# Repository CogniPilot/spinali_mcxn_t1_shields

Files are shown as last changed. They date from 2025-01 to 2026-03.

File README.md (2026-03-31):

# MR-MCXN-T1 Add-on boards

> [!NOTE]
> Different Add-on boards have been designed for the modular multi-purpose [MR-MCXN-T1 Hub](https://github.com/CogniPilot/spinali_mcxn_t1_hub). 
>
> The following add-on boards have been designed:
> - Optical Flow
> - IO
> - GNSS (with F9P module) [^1]
> 
> All add-on boards are designed with KiCAD.
>
> [^1]: GNSS add-on is still in the design process.

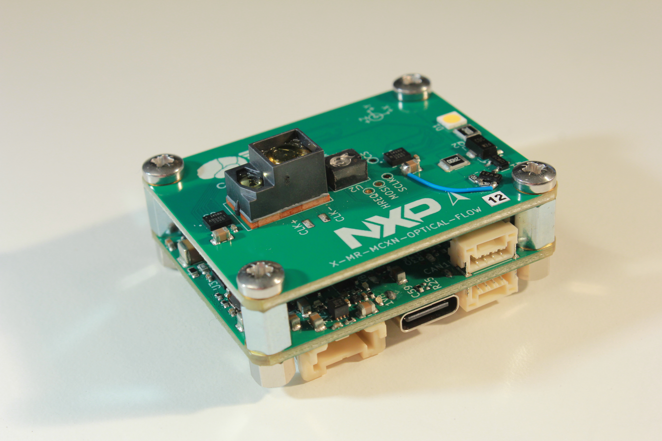
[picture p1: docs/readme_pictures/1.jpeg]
Hub with Optical Flow add-on

<sup>Example of Optical Flow add-on board stacked on MR-MCXN-T1 Hub</sup>

# MR-MCXN-T1 Optical Flow

> [!NOTE]
> The Optical Flow add-on board can be used in for instance UAVs and UGVs for localization and navigation using the following on-board sensors:
> - Time of Flight (AFBR-S50LX85D)
> - Optical Flow (PAA3905E1) + required light source
> - IMU 2x (ICM-45686 & ICM42688)

<details>
<summary>MR-MCXN-T1 Optical Flow pictures</summary>
  
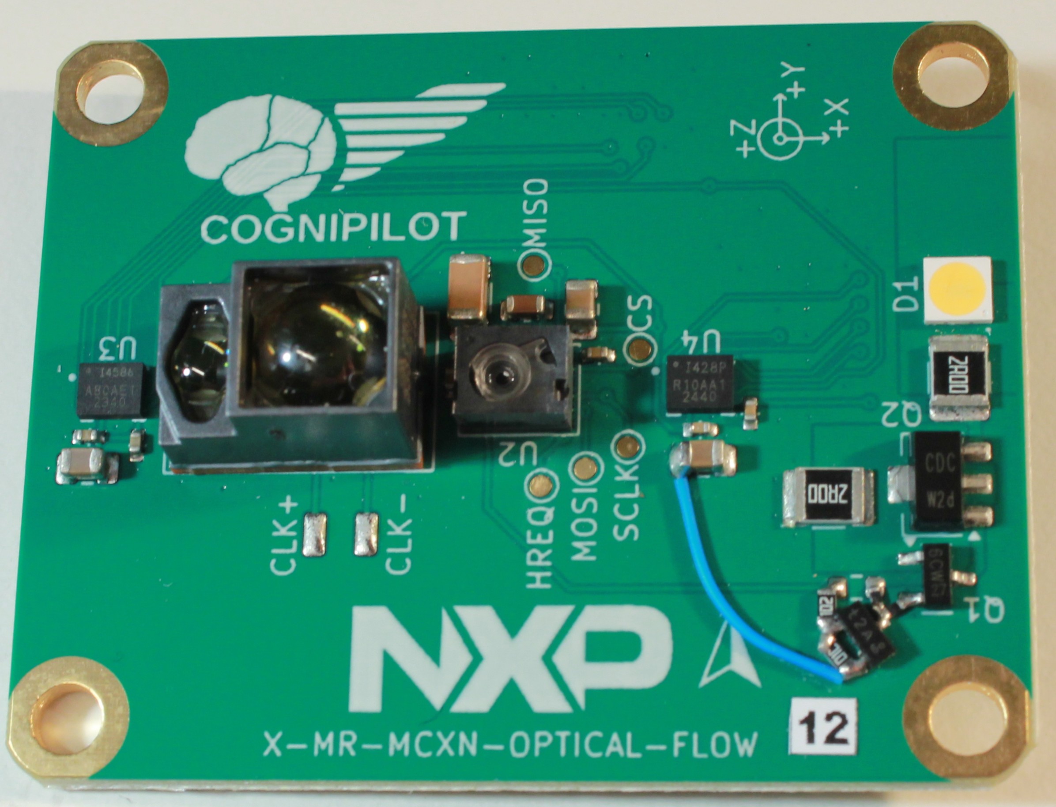
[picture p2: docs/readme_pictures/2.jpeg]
Optical Flow Cropped

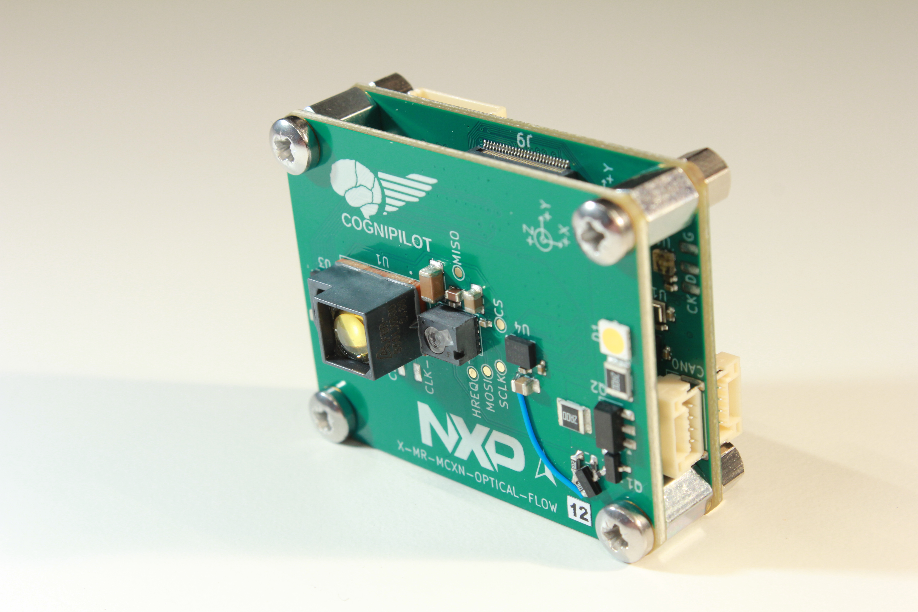
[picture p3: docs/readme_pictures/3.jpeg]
Optical Flow Side


</details>

# MR-MCXN-T1 IO

> [!Note]
> MR-MCXN-T1 IO board brings out almost all GPIO to JST connectors. These are as follows:
> | IO type      | Connector type |
> | ----------- | ----------- |
> | UART 2x | JST GH 6-pin |
> | SPI 2x | JST GH 7-pin |
> | I2C 2x | JST GH 4-pin |
> | GPS | JST GH 10-pin |
> | Quadrature Decoder | JST GH 6-pin |
> | 4in1 ESC 2x | JST GH 8-pin |
> | External battery input for RTC | JST GH 2-pin |
> 
> If applicable the connector pinouts follow the [DS-009 Connector Standard](https://github.com/pixhawk/Pixhawk-Standards/blob/master/DS-009%20Pixhawk%20Connector%20Standard.pdf).

<details>
<summary>MR-MCXN-T1 IO pictures</summary>
  
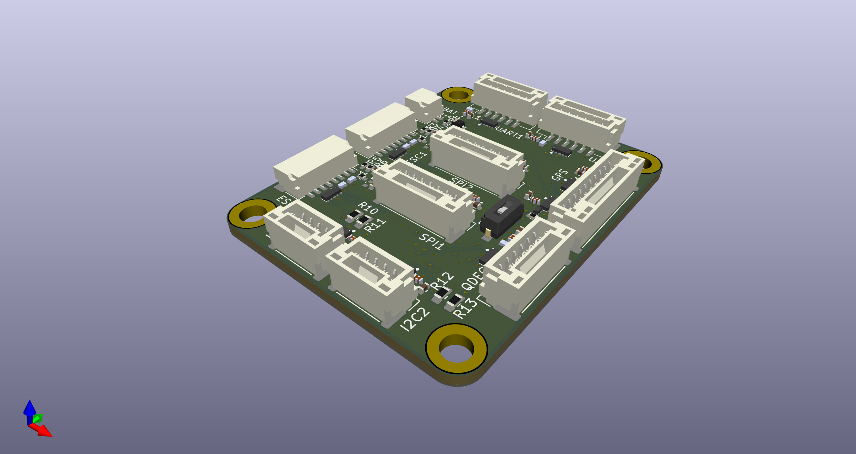
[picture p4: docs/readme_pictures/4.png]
IO Board Side

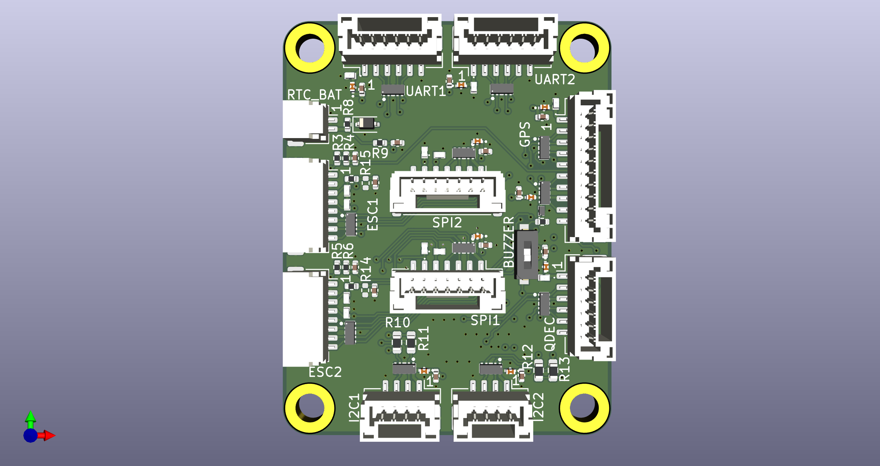
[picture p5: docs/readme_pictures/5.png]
IO Board Top


</details>

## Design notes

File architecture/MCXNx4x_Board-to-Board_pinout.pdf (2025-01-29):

X0A | | Pin | Pad type | ADC | Optical flow | Mikrobus adapter | GPS | Optical flow + GPS | Camera head | Display | Microphone | Opamp | Motor control | Dual motor control | Speaker driver | SDIO shield | Trace DBG
1 PGND
3 5V
5 5V
7 5V
9 PGND
11 PGND
13 VDD_BAT
15 3V3
17 | T17 | 3V3
19 PGND
21 PGND
23 | P4_0 | FC2_P0 | slow | | | | | FC2_P0
25 | P4_1 | FC2_P1 | slow | | | | | FC2_P1
27 GND
29 | P4_2 | FC2_P2 | slow | ADC0_A4/ADC1_A4 | | | | FC2_P2 | | | | | CMP1_IN4N | CMP1_IN4N | DAC0_OUT
31 | P4_3 | FC2_P3 | slow | ADC0_B4/ADC1_B4 | | | | FC2_P3 | | | | | CMP1_IN5N | CMP1_IN5N | DAC1_OUT
33 GND
35 | P4_23 | FC2_P6 | slow | ADC0_A2/ADC0_B2/ADC1_B3 | | | | FC2_P6 | | | | OPAMP2_OUT | | CMP2_IN4P
37 | P4_20 | FC2_P4 | slow | ADC1_A6 | | | | FC2_P4 | | FLEXIO0_D28 | | OPAMP2_INP0
39 GND
41 | ANA_22 | OPAMP2_INN | | | | | | | | | | OPAMP2_INN
43 | ANA_6 | DAC2_OUT | | ADC0_A3/ADC1_A3 | | | | | | | | | | | DAC2_OUT
45 GND
47 | P0_23 | FLEXIO0_D7 | med | ADC0_A15 | | | | | | FLEXIO0_D7 | | | | CMP2_IN2
49 GND
X0B | | Pin | Pad type | ADC | Optical flow | Mikrobus adapter | GPS | Optical flow + GPS | Camera head | Display | Microphone | Opamp | Motor control | Dual motor control | Speaker driver | SDIO shield | Trace DBG
2 PGND
4 5V
6 5V
8 5V
10 PGND
12 PGND
14 3V3
16 3V3
18 PGND
20 PGND
22 1V8
24 PGND
26 | P1_8 | FC4_P0 | med | ADC1_A8 | I3C1_SDA | ADC1_A8 | | I3C1_SDA | I3C1_SDA
28 | P1_9 | FC4_P1 | med | ADC1_A9 | I3C1_SCL | ADC1_A9 | | I3C1_SCL | I3C1_SCL
30 GND
32 | P3_1 | FC6_P0 | fast | | SPI_SDO | SPI_SDO | | SPI_SDO | SmartDMA_PIO1 | | | | | PWM0_B0
34 | P3_6 | FC6_P1 | fast | | SPI_SCK | SPI_SCK | | SPI_SCK | SmartDMA_PIO6 | | | | | PWM0_A1
36 GND
38 | P3_10 | FC6_P2 | fast | | SPI_SDI | SPI_SDI | | SPI_SDI | SmartDMA_PIO10 | FLEXIO0_D18 | | | | PWM0_A3
40 | P3_11 | FC6_P3 | fast | | SPI_CS0 | SPI_CS0 | | SPI_CS0 | SmartDMA_PIO11 | FLEXIO0_D19 | | | | PWM0_B3
42 | P3_18 | FC6_P6 | fast | | SPI_HREQ | SPI_HREQ | | SPI_HREQ | SmartDMA_PIO18
44 GND
46 | 2_10 | TRACE_DATA2 | fast | | | | | | | | | | | | | | TRACE_DATA2
48 | 2_11 | TRACE_DATA3 | fast | | | | | | | | | | | | | | TRACE_DATA3
50 GND

X1A | | Pin | Pad type | ADC | Optical flow | Mikrobus adapter | GPS | Optical flow + GPS | Camera head | Display | Microphone | Opamp | Motor control | Dual motor control | Speaker driver | SDIO shield | Trace DBG
1 GND
3 | P2_5 | uSDHC0_CMD | fast | | FC9_P2 | SPI_SDI | | FC9_P2 | SmartDMA_PIO25 | FLEXIO0_D13 | | | PWM1_B1 | PWM1_B1 | SAI0_TXD1 | uSDHC0_CMD
5 | P2_4 | uSDHC0_CLK | fast | | FC9_P0 | SPI_SDO | | FC9_P0 | SmartDMA_PIO24 | FLEXIO0_D12 | | | PWM1_A1 | PWM1_A1 | SAI0_RXD1 | uSDHC0_CLK
7 GND
9 | P2_3 | uSDHC0_D0 | fast | | FC9_P1 | SPI_SCK | | FC9_P1 | SmartDMA_PIO23 | FLEXIO0_D11 | | | PWM1_B2 | PWM1_B2 | SAI0_RXD0 | uSDHC0_D0
11 | P2_2 | uSDHC0_D1 | fast | | FC9_P3 | SPI_CS0 | | FC9_P3 | CLKOUT | FLEXIO0_D10 | | | PWM1_A2 | PWM1_A2 | SAI0_TXD0 | uSDHC0_D1
13 GND
15 | P2_7 | uSDHC0_D2 | fast | | | | | | SmartDMA_PIO27 | FLEXIO0_D15 | | | PWM1_B0 | PWM1_B0 | SAI0_TX_FS | uSDHC0_D2
17 | P2_6 | uSDHC0_D3 | fast | | | PWM1_A0 | | | SmartDMA_PIO26 | FLEXIO0_D14 | | | PWM1_A0 | PWM1_A0 | SAI0_TX_BCLK | uSDHC0_D3
19 GND
21 | P2_1 | uSDHC0_D4 | fast | | | RST2 | | | SmartDMA_PIO21 | FLEXIO0_D9 | | | PWM1_B3 | PWM1_B3 | SAI0_RX_FS | uSDHC0_D4 | TRACE_CLK
23 | P2_0 | uSDHC0_D5 | fast | | FC9_P6 | SPI_HREQ | | FC9_P6 | SmartDMA_PIO20 | FLEXIO0_D8 | | | PWM1_A3 | PWM1_A3 | SAI0_RX_BCLK | uSDHC0_D5
25 GND
27 | P2_9 | uSDHC0_D6 | fast | | | RST1 | | | SmartDMA_PIO29 | FLEXIO0_D17 | | | | | | uSDHC0_D6 | TRACE_DATA1
29 | P2_8 | uSDHC0_D7 | fast | | | | | | SmartDMA_PIO28 | FLEXIO0_D16 | | | | | | uSDHC0_D7 | TRACE_DATA0
31 GND
33 | P3_2 | FC7_P0 | fast | | SPI_SDO | I2C_SDA | FC7_P0 | SPI_SDO | I2C_SDA
35 | P3_3 | FC7_P1 | fast | | SPI_SCK | I2C_SCL | FC7_P1 | SPI_SCK | I2C_SCL
37 GND
39 | P3_4 | FC7_P2 | fast | | SPI_SDI | UART_TXD | FC7_P2 | SPI_SDI | UART_TXD
41 | P3_5 | FC7_P3 | fast | | SPI_CS0 | UART_RXD | FC7_P3 | SPI_CS0 | UART_RXD
43 GND
45 | P3_19 | FC7_P6 | fast | | SPI_HREQ | HREQ | FC7_P6 | SPI_HREQ | HREQ | FLEXIO0_D27
47 | P3_12 | FC7_P4 | fast | | | | | | SmartDMA_PIO12 | FLEXIO0_D20
49 GND
X1B | | Pin | Pad type | ADC | Optical flow | Mikrobus adapter | GPS | Optical flow + GPS | Camera head | Display | Microphone | Opamp | Motor control | Dual motor control | Speaker driver | SDIO shield | Trace DBG
2 GND
4 | P3_0 | SmartDMA_PIO0 | fast | | | PWM0_A0 | | | SmartDMA_PIO0 | | | | | PWM0_A0
6 | P3_7 | SmartDMA_PIO7 | fast | | | | | | SmartDMA_PIO7 | | | | | PWM0_B1
8 GND
10 | P3_8 | SmartDMA_PIO8 | fast | | | | | | SmartDMA_PIO8 | | | | | PWM0_A2
12 | P3_9 | SmartDMA_PIO9 | fast | | | | | | SmartDMA_PIO9 | | | | | PWM0_B2
14 GND
16 | P1_0 | FC3_P0 | med | ADC0_A16 | | I2C_SDA | | | | I2C_SDA | | | ADC0_A16 | ADC0_A16
18 | P1_1 | FC3_P1 | med | ADC0_A17 | | I2C_SCL | | | | I2C_SCL | | | CMP1_IN0 | CMP1_IN0
20 GND
22 | P1_2 | FC3_P2 | med | ADC0_A18 | | UART_TXD | | | | | | | | CMP2_IN0
24 | P1_3 | FC3_P3 | med | ADC0_A19 | | UART_RXD | | | | | | | ADC0_A19 | ADC0_A19
26 GND
28 | P1_18 | FC3_P6 | med | ADC1_A18 | | HREQ | | | SmartDMA_PIO14 | FLEXIO0_D26
30 GND
32 | P1_16 | FC3_P4 | med | ADC1_A16 | FC5_P0 | | | | | FLEXIO0_D24
34 | P1_17 | FC3_P5 | med | ADC1_A17 | FC5_P1 | | | | | FLEXIO0_D25
36 GND
38 | P0_16 | FC0_P0 | med | ADC0_A8 | | ADC0_A8 | | | | | PDM0_CLK | | | ADC0_A8
40 | P0_17 | FC0_P1 | med | ADC0_A9 | | | | | | | PDM0_DATA0 | | | ADC0_A9
42 GND
44 | P0_18 | FC0_P2 | med | ADC0_A10 | | ADC0_A10 | | | | | PDM0_DATA1 | | | ADC0_A10
46 | P0_7 | FC0_P3 | med | | | | | | | | | | | CMP2_IN1
48 | P0_22 | FC0_P6 | med | ADC0_A14 | | | | | | FLEXIO0_D6 | | | CMP1_IN2 | CMP1_IN2
50 GND

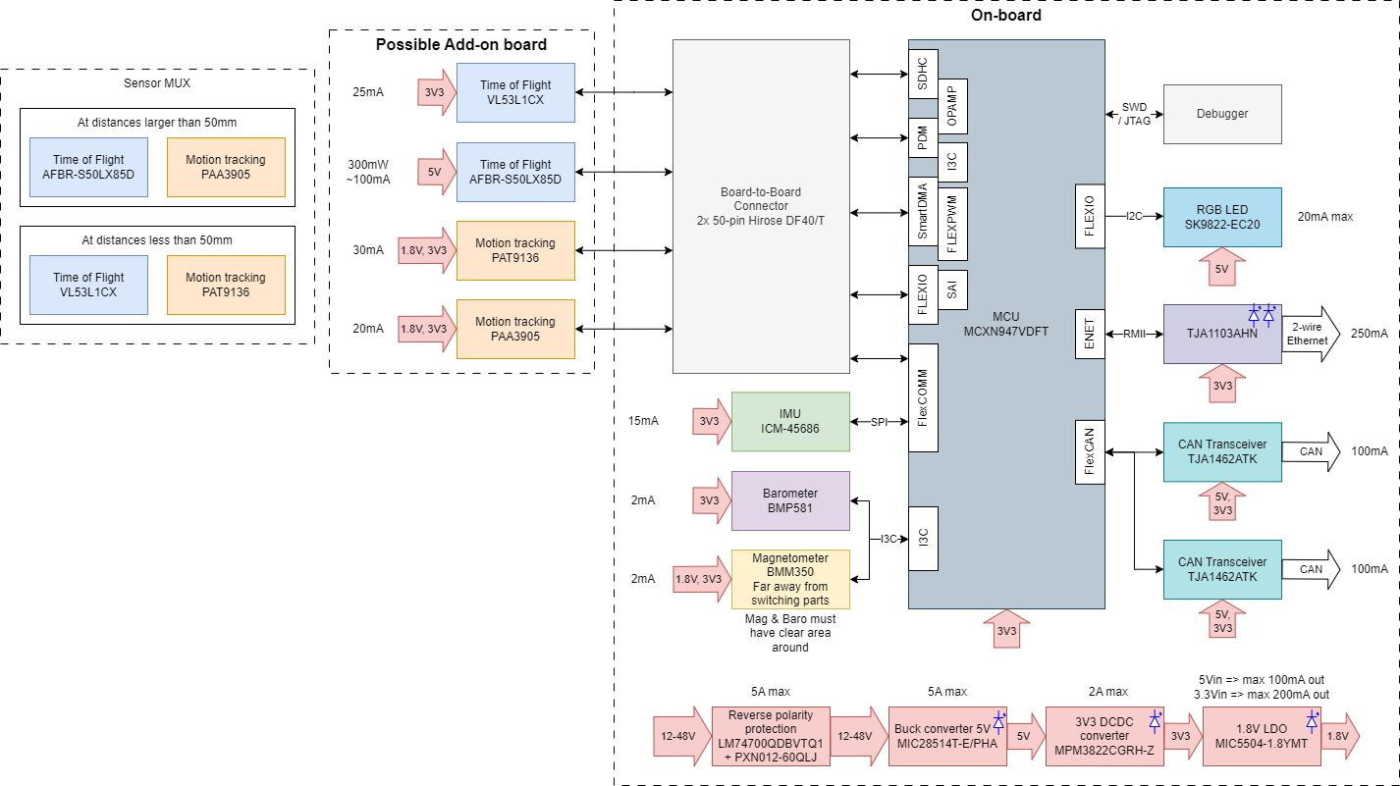
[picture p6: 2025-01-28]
architecture/Architecture diagram-New Concept modulair Sensor hub.drawio.png

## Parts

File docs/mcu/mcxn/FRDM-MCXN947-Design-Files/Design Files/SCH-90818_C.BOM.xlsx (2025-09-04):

 | ManufacturerBomReport
Type | Part
Classification | Sales Item/Commercial Boards/Evaluation Board or Silicon Validation
Item Number | 935455837598
Name | FRDM-MCXN947
Description | FRDM-MCXN947
Lifecycle | RFS
Item Revision | A1
Change Item
Created By: | Kate Fan
Create Time: | 4/1/2024 4:59 AM
Level | Type | Classification | Item Number | Name | Description | Lifecycle | Item Revision | Change Item | Quantity | Reference Designator | Find Num | BOM Notes | Manufacturer Item Number | Manufacturer Name | Manufacturer | Manufacturer Lifecycle | Manufacturer Notes | Preferred Status
0 | Part | Sales Item/Commercial Boards/Evaluation Board or Silicon Validation | 935455837598 | FRDM-MCXN947 | FRDM-MCXN947 | RFS | A1 |  |  |  |  |  | 246025 | FRDM-MCXN947 | Trivo (Taicang) Technologies Co Ltd | Active |  | Preferred
1 | Part | Boards/Non CAD Parts/Assembly | 745000379172 | 975-90818 | HW PACKOUT, FRDM-MCXN947 | RFS | A1 | ECO30008196 | 1 |  | 1
2 | Part | Boards/CAD Parts/Component | 745000042610 | 211-79847 | SHUNT -- 0.1IN SP JMPR -- AU BLACK | RFS | A |  | 2 |  | 50 |  | 285268 | M7582-05 | HARWIN INC | ROHS Active |  | Preferred
2 | Part | Boards/CAD Parts/Component | 745000042610 | 211-79847 | SHUNT -- 0.1IN SP JMPR -- AU BLACK | RFS | A |  | 2 |  | 50 |  | 299066 | SNT-100-BK-G | SAMTEC | ROHS Active |  | Preferred
2 | Part | Boards/Non CAD Parts/Assembly | 745000281407 | 700-90818 | PWA, FRDM-MCXN947 | RFS | A1 | ECO30010456 | 1 |  | 40 |  | 219145 | 700-90818 | Trivo (Taicang) Technologies Co Ltd | ROHS Active |  | Preferred
2 | Part | Boards/Non CAD Parts/Assembly | 745000281407 | 700-90818 | PWA, FRDM-MCXN947 | RFS | A1 | ECO30010456 | 1 |  | 40 |  | 314140 | 700-90818 | ZHE JIANG XIAN XIN SCIENCE AND TECHNOLOGY CO.LTD | ROHS Active
3 | Part | Boards/Non CAD Parts/Assembly | 745000312196 | 750-90818 | SUB ASSEMBLY, SCHEMATIC PARTS, 700-90818, FRDM-MCXN947 | RFS | C | ECO30010345 | 1 |  | 1000
4 | Part | Boards/CAD Parts/Component | 745000012851 | 150-78886 | CAP CER 0.22UF 16V 10% X7R 0402 | RFS | A |  | 4 | C26,C38,C40,C41 | 0 |  | 200381 | 0402B224K160CT | WALSIN TECHNOLOGY CORP. | Active |  | Preferred
4 | Part | Boards/CAD Parts/Component | 745000012851 | 150-78886 | CAP CER 0.22UF 16V 10% X7R 0402 | RFS | A |  | 4 | C26,C38,C40,C41 | 0 |  | 200603 | 0402B224K160NT | FENGHUA | ROHS Active |  | Alternate
4 | Part | Boards/CAD Parts/Component | 745000012851 | 150-78886 | CAP CER 0.22UF 16V 10% X7R 0402 | RFS | A |  | 4 | C26,C38,C40,C41 | 0 |  | 247691 | GRM155R71C224KA12D | MURATA | Active |  | Alternate
4 | Part | Boards/CAD Parts/Component | 745000013109 | 150-79188 | CAP CER 100pF 16V 10% X7R 0402 | RFS | A |  | 1 | C63 | 0 |  | 200554 | 0402YC101KAT2A | AVX | Active |  | Preferred
4 | Part | Boards/CAD Parts/Component | 745000013463 | 150-79569 | CAP CER 10uF 25V 10% X5R 0603 | RFS | A |  | 0 | C72,C73,C74,C75 | 1504 | DNP | 228855 | C0603X5R106K250NT | SANYEAR | ROHS Active |  | Preferred
4 | Part | Boards/CAD Parts/Component | 745000013463 | 150-79569 | CAP CER 10uF 25V 10% X5R 0603 | RFS | A |  | 9 | C37,C62,C69,C70,C71,C83,C84,C104,C105 | 0 |  | 228855 | C0603X5R106K250NT | SANYEAR | ROHS Active |  | Preferred
4 | Part | Boards/CAD Parts/Component | 745000014519 | 150-80750 | CAP CER 4.7PF 50V 0.5pF C0G 0402 | RFS | A |  | 4 | C1,C2,C100,C101 | 0 |  | 239686 | 885012005053 | WURTH ELEKTRONIK EISOS GMBH & CO. KG (ELECTRONIC & ELECTROMEHANICAL COMP) | Active |  | Preferred
4 | Part | Boards/CAD Parts/Component | 745000015307 | 150-81667 | CAP CER 15pF 50V 5% C0G 0402 | RFS | A |  | 0 | C54,C55,C56,C57 | 1502 | DNP | 273304 | GJM1555C1H150JB01D | MURATA | ROHS Active |  | Preferred
4 | Part | Boards/CAD Parts/Component | 745000047746 | 210-81775 | CON 2X8 SKT SHRD TH 100MIL CTR 345H AU 126L | RFS | A |  | 2 | J1,J3 | 0 |  | 201294 | 08010S31611-29RF | ANYTRONIC CORPORATION LIMITED | ROHS Active |  | Preferred
4 | Part | Boards/CAD Parts/Component | 745000049109 | 210-83442 | CON 2X14 SKT SHRD TH 100MIL CTR 345H AU 126L | RFS | A |  | 1 | J8 | 0 |  | 201317 | 08010S32811-29RF | ANYTRONIC CORPORATION LIMITED | ROHS Active |  | Preferred
4 | Part | Boards/CAD Parts/Component | 745000031874 | 230-78687 | OSC XO 50MHZ 3.3V SMD | RFS | A |  | 1 | Y3 | 0 |  | 266009 | ECS-2333-500-BN-TR | ECS INC. INTERNATIONAL | ROHS Active |  | Preferred
4 | Part | Boards/CAD Parts/Component | 745000019445 | 312-81574 | IC USB PD TYPE C CURRENT LIMITED PWR SW 2.5-5.5V WLCSP12 | RFS | A |  | 1 | U3 | 0 |  | 289609 | NX5P3090UK,012 | NXP SEMICONDUCTOR | Active | Pb-free assembly 260 °C | Preferred
4 | Part | Boards/CAD Parts/Component | 745000019445 | 312-81574 | IC USB PD TYPE C CURRENT LIMITED PWR SW 2.5-5.5V WLCSP12 | RFS | A |  | 1 | U3 | 0 |  | 291065 | NX5P3090UKZ | NXP SEMICONDUCTOR | Active |  | Alternate
4 | Part | Boards/CAD Parts/Component | 745000020844 | 312-83230 | IC XCVR CAN 5MBIT/S 4.75-5.25V AEC-Q100 HVSON8 | RFS | A |  | 1 | U10 | 0 |  | 298760 | TJA1057GTK/3Z | NXP SEMICONDUCTOR | ROHS Active |  | Preferred
4 | Part | Boards/CAD Parts/Component | 745000033390 | 470-30315 | RES MF 470 OHM 1/16W 5% 0402 | RFS | A |  | 10 | R4,R5,R6,R7,R24,R66,R69,R108,R109,R114 | 0 |  | 267838 | ERJ2GEJ471X | PANASONIC | ROHS Active |  | Alternate
4 | Part | Boards/CAD Parts/Component | 745000033390 | 470-30315 | RES MF 470 OHM 1/16W 5% 0402 | RFS | A |  | 10 | R4,R5,R6,R7,R24,R66,R69,R108,R109,R114 | 0 |  | 269357 | RC0402JR-07470RL | YAGEO AMERICA | ROHS Active |  | Alternate
4 | Part | Boards/CAD Parts/Component | 745000033390 | 470-30315 | RES MF 470 OHM 1/16W 5% 0402 | RFS | A |  | 10 | R4,R5,R6,R7,R24,R66,R69,R108,R109,R114 | 0 |  | 293195 | RC73L2Z471JTF | SMEC | ROHS Active | Material Declaration is not available at this time. | Preferred
4 | Part | Boards/CAD Parts/Component | 745000034521 | 470-75394 | RES MF ZERO OHM 1/16W 5% 0402 | RFS | A1 |  | 17 | R27,R47,R48,R110,R111,R129,R130,R132,R133,R167,R169,R198,R199,R200,R201,R202,R203 | 0 |  | 230716 | CR-02JL6----0R | THYE MING TECH CO LTD | ROHS Active | No MDS available per Mfg | Alternate
4 | Part | Boards/CAD Parts/Component | 745000034521 | 470-75394 | RES MF ZERO OHM 1/16W 5% 0402 | RFS | A1 |  | 17 | R27,R47,R48,R110,R111,R129,R130,R132,R133,R167,R169,R198,R199,R200,R201,R202,R203 | 0 |  | 230832 | CR0402-J/-000GLF | BOURNS | ROHS Active |  | Alternate
4 | Part | Boards/CAD Parts/Component | 745000034521 | 470-75394 | RES MF ZERO OHM 1/16W 5% 0402 | RFS | A1 |  | 17 | R27,R47,R48,R110,R111,R129,R130,R132,R133,R167,R169,R198,R199,R200,R201,R202,R203 | 0 |  | 252957 | CR0402-16W-000T | VENKEL COMPANY | ROHS Active |  | Alternate
4 | Part | Boards/CAD Parts/Component | 745000034521 | 470-75394 | RES MF ZERO OHM 1/16W 5% 0402 | RFS | A1 |  | 17 | R27,R47,R48,R110,R111,R129,R130,R132,R133,R167,R169,R198,R199,R200,R201,R202,R203 | 0 |  | 244207 | ERJ2GE0R00X | PANASONIC | ROHS Active |  | Alternate
4 | Part | Boards/CAD Parts/Component | 745000034521 | 470-75394 | RES MF ZERO OHM 1/16W 5% 0402 | RFS | A1 |  | 17 | R27,R47,R48,R110,R111,R129,R130,R132,R133,R167,R169,R198,R199,R200,R201,R202,R203 | 0 |  | 254525 | MCR01MZPJ000 | ROHM | ROHS Active | ROHS Compliant | Preferred
4 | Part | Boards/CAD Parts/Component | 745000034521 | 470-75394 | RES MF ZERO OHM 1/16W 5% 0402 | RFS | A1 |  | 17 | R27,R47,R48,R110,R111,R129,R130,R132,R133,R167,R169,R198,R199,R200,R201,R202,R203 | 0 |  | 263983 | RC-0402-0000T | SKYMOS | ROHS Active | no MDS available | Alternate
4 | Part | Boards/CAD Parts/Component | 745000034521 | 470-75394 | RES MF ZERO OHM 1/16W 5% 0402 | RFS | A1 |  | 17 | R27,R47,R48,R110,R111,R129,R130,R132,R133,R167,R169,R198,R199,R200,R201,R202,R203 | 0 |  | 265937 | RK73Z1ETTP | KOA SPEER | ROHS Active |  | Alternate
4 | Part | Boards/CAD Parts/Component | 745000034521 | 470-75394 | RES MF ZERO OHM 1/16W 5% 0402 | RFS | A1 |  | 17 | R27,R47,R48,R110,R111,R129,R130,R132,R133,R167,R169,R198,R199,R200,R201,R202,R203 | 0 |  | 264257 | RC73JP2ZF | SMEC | ROHS Active |  | Alternate
4 | Part | Boards/CAD Parts/Component | 745000034521 | 470-75394 | RES MF ZERO OHM 1/16W 5% 0402 | RFS | A1 |  | 17 | R27,R47,R48,R110,R111,R129,R130,R132,R133,R167,R169,R198,R199,R200,R201,R202,R203 | 0 |  | 271567 | RMCF1/16S0.005%R | SEI ELECTRONICS INC | ROHS Active |  | Alternate
4 | Part | Boards/CAD Parts/Component | 745000034521 | 470-75394 | RES MF ZERO OHM 1/16W 5% 0402 | RFS | A1 |  | 17 | R27,R47,R48,R110,R111,R129,R130,R132,R133,R167,R169,R198,R199,R200,R201,R202,R203 | 0 |  | 292855 | RC0402JR-070RL | YAGEO AMERICA | ROHS Active |  | Alternate
4 | Part | Boards/CAD Parts/Component | 745000034521 | 470-75394 | RES MF ZERO OHM 1/16W 5% 0402 | RFS | A1 |  | 17 | R27,R47,R48,R110,R111,R129,R130,R132,R133,R167,R169,R198,R199,R200,R201,R202,R203 | 0 |  | 302450 | WR04X000_PTL | WALSIN TECHNOLOGY CORP. | ROHS Active |  | Alternate
4 | Part | Boards/CAD Parts/Component | 745000034521 | 470-75394 | RES MF ZERO OHM 1/16W 5% 0402 | RFS | A1 |  | 0 | R43,R45,R46,R131,R136,R137,R138,R139,R142,R143 | 4703 | DNP | 230716 | CR-02JL6----0R | THYE MING TECH CO LTD | ROHS Active | No MDS available per Mfg | Alternate
4 | Part | Boards/CAD Parts/Component | 745000034521 | 470-75394 | RES MF ZERO OHM 1/16W 5% 0402 | RFS | A1 |  | 0 | R43,R45,R46,R131,R136,R137,R138,R139,R142,R143 | 4703 | DNP | 230832 | CR0402-J/-000GLF | BOURNS | ROHS Active |  | Alternate
4 | Part | Boards/CAD Parts/Component | 745000034521 | 470-75394 | RES MF ZERO OHM 1/16W 5% 0402 | RFS | A1 |  | 0 | R43,R45,R46,R131,R136,R137,R138,R139,R142,R143 | 4703 | DNP | 252957 | CR0402-16W-000T | VENKEL COMPANY | ROHS Active |  | Alternate
4 | Part | Boards/CAD Parts/Component | 745000034521 | 470-75394 | RES MF ZERO OHM 1/16W 5% 0402 | RFS | A1 |  | 0 | R43,R45,R46,R131,R136,R137,R138,R139,R142,R143 | 4703 | DNP | 244207 | ERJ2GE0R00X | PANASONIC | ROHS Active |  | Alternate
4 | Part | Boards/CAD Parts/Component | 745000034521 | 470-75394 | RES MF ZERO OHM 1/16W 5% 0402 | RFS | A1 |  | 0 | R43,R45,R46,R131,R136,R137,R138,R139,R142,R143 | 4703 | DNP | 254525 | MCR01MZPJ000 | ROHM | ROHS Active | ROHS Compliant | Preferred
4 | Part | Boards/CAD Parts/Component | 745000034521 | 470-75394 | RES MF ZERO OHM 1/16W 5% 0402 | RFS | A1 |  | 0 | R43,R45,R46,R131,R136,R137,R138,R139,R142,R143 | 4703 | DNP | 263983 | RC-0402-0000T | SKYMOS | ROHS Active | no MDS available | Alternate
4 | Part | Boards/CAD Parts/Component | 745000034521 | 470-75394 | RES MF ZERO OHM 1/16W 5% 0402 | RFS | A1 |  | 0 | R43,R45,R46,R131,R136,R137,R138,R139,R142,R143 | 4703 | DNP | 265937 | RK73Z1ETTP | KOA SPEER | ROHS Active |  | Alternate
4 | Part | Boards/CAD Parts/Component | 745000034521 | 470-75394 | RES MF ZERO OHM 1/16W 5% 0402 | RFS | A1 |  | 0 | R43,R45,R46,R131,R136,R137,R138,R139,R142,R143 | 4703 | DNP | 264257 | RC73JP2ZF | SMEC | ROHS Active |  | Alternate
4 | Part | Boards/CAD Parts/Component | 745000034521 | 470-75394 | RES MF ZERO OHM 1/16W 5% 0402 | RFS | A1 |  | 0 | R43,R45,R46,R131,R136,R137,R138,R139,R142,R143 | 4703 | DNP | 271567 | RMCF1/16S0.005%R | SEI ELECTRONICS INC | ROHS Active |  | Alternate
4 | Part | Boards/CAD Parts/Component | 745000034521 | 470-75394 | RES MF ZERO OHM 1/16W 5% 0402 | RFS | A1 |  | 0 | R43,R45,R46,R131,R136,R137,R138,R139,R142,R143 | 4703 | DNP | 292855 | RC0402JR-070RL | YAGEO AMERICA | ROHS Active |  | Alternate
4 | Part | Boards/CAD Parts/Component | 745000034521 | 470-75394 | RES MF ZERO OHM 1/16W 5% 0402 | RFS | A1 |  | 0 | R43,R45,R46,R131,R136,R137,R138,R139,R142,R143 | 4703 | DNP | 302450 | WR04X000_PTL | WALSIN TECHNOLOGY CORP. | ROHS Active |  | Alternate
4 | Part | Boards/CAD Parts/Component | 745000034893 | 470-76037 | RES MF 1.0K 1/16W 1% 0402 | RFS | A1 |  | 0 | R118,R119,R121,R123 | 4705 | DNP | 234366 | CR-02FL6----1K | THYE MING TECH CO LTD | ROHS Active | No MDS available per Mfg | Alternate
4 | Part | Boards/CAD Parts/Component | 745000034893 | 470-76037 | RES MF 1.0K 1/16W 1% 0402 | RFS | A1 |  | 0 | R118,R119,R121,R123 | 4705 | DNP | 254268 | CRCW04021K00FKEDC | VISHAY | Active |  | Alternate
4 | Part | Boards/CAD Parts/Component | 745000034893 | 470-76037 | RES MF 1.0K 1/16W 1% 0402 | RFS | A1 |  | 0 | R118,R119,R121,R123 | 4705 | DNP | 255279 | CR0402-FX-1001GLF | BOURNS | Active |  | Alternate
4 | Part | Boards/CAD Parts/Component | 745000034893 | 470-76037 | RES MF 1.0K 1/16W 1% 0402 | RFS | A1 |  | 0 | R118,R119,R121,R123 | 4705 | DNP | 264008 | RC0402FR-071KL | YAGEO AMERICA | ROHS Active | no md available | Preferred
4 | Part | Boards/CAD Parts/Component | 745000034893 | 470-76037 | RES MF 1.0K 1/16W 1% 0402 | RFS | A1 |  | 0 | R118,R119,R121,R123 | 4705 | DNP | 281103 | WR04X1001FTL | WALSIN TECHNOLOGY CORP. | ROHS Active |  | Alternate
4 | Part | Boards/CAD Parts/Component | 745000034893 | 470-76037 | RES MF 1.0K 1/16W 1% 0402 | RFS | A1 |  | 4 | R53,R117,R120,R122 | 0 |  | 234366 | CR-02FL6----1K | THYE MING TECH CO LTD | ROHS Active | No MDS available per Mfg | Alternate
4 | Part | Boards/CAD Parts/Component | 745000034893 | 470-76037 | RES MF 1.0K 1/16W 1% 0402 | RFS | A1 |  | 4 | R53,R117,R120,R122 | 0 |  | 254268 | CRCW04021K00FKEDC | VISHAY | Active |  | Alternate
4 | Part | Boards/CAD Parts/Component | 745000034893 | 470-76037 | RES MF 1.0K 1/16W 1% 0402 | RFS | A1 |  | 4 | R53,R117,R120,R122 | 0 |  | 255279 | CR0402-FX-1001GLF | BOURNS | Active |  | Alternate
4 | Part | Boards/CAD Parts/Component | 745000034893 | 470-76037 | RES MF 1.0K 1/16W 1% 0402 | RFS | A1 |  | 4 | R53,R117,R120,R122 | 0 |  | 264008 | RC0402FR-071KL | YAGEO AMERICA | ROHS Active | no md available | Preferred
4 | Part | Boards/CAD Parts/Component | 745000034893 | 470-76037 | RES MF 1.0K 1/16W 1% 0402 | RFS | A1 |  | 4 | R53,R117,R120,R122 | 0 |  | 281103 | WR04X1001FTL | WALSIN TECHNOLOGY CORP. | ROHS Active |  | Alternate
4 | Part | Boards/CAD Parts/Component | 745000036635 | 470-80452 | RES MF 10K 1/16W 1% 0402 | RFS | A |  | 0 | R37,R38,R40,R42,R49,R50,R97 | 4702 | DNP | 235532 | CRCW040210K0FKEDC | VISHAY | ROHS Active |  | Alternate
4 | Part | Boards/CAD Parts/Component | 745000036635 | 470-80452 | RES MF 10K 1/16W 1% 0402 | RFS | A |  | 0 | R37,R38,R40,R42,R49,R50,R97 | 4702 | DNP | 292775 | RC0402FR-0710KL | Yageo | Active | Reflow Profiles 260 °C | Alternate
4 | Part | Boards/CAD Parts/Component | 745000036635 | 470-80452 | RES MF 10K 1/16W 1% 0402 | RFS | A |  | 0 | R37,R38,R40,R42,R49,R50,R97 | 4702 | DNP | 290750 | NRCL04F1002TRF | NIC COMPONENTS CORP | Active |  | Preferred
4 | Part | Boards/CAD Parts/Component | 745000036635 | 470-80452 | RES MF 10K 1/16W 1% 0402 | RFS | A |  | 0 | R37,R38,R40,R42,R49,R50,R97 | 4702 | DNP | 294588 | RC0402FR-1310KL | Yageo | Active |  | Alternate
4 | Part | Boards/CAD Parts/Component | 745000036635 | 470-80452 | RES MF 10K 1/16W 1% 0402 | RFS | A |  | 16 | R1,R2,R3,R21,R26,R36,R39,R41,R57,R58,R59,R60,R86,R106,R116,R207 | 0 |  | 235532 | CRCW040210K0FKEDC | VISHAY | ROHS Active |  | Alternate
4 | Part | Boards/CAD Parts/Component | 745000036635 | 470-80452 | RES MF 10K 1/16W 1% 0402 | RFS | A |  | 16 | R1,R2,R3,R21,R26,R36,R39,R41,R57,R58,R59,R60,R86,R106,R116,R207 | 0 |  | 292775 | RC0402FR-0710KL | Yageo | Active | Reflow Profiles 260 °C | Alternate
4 | Part | Boards/CAD Parts/Component | 745000036635 | 470-80452 | RES MF 10K 1/16W 1% 0402 | RFS | A |  | 16 | R1,R2,R3,R21,R26,R36,R39,R41,R57,R58,R59,R60,R86,R106,R116,R207 | 0 |  | 290750 | NRCL04F1002TRF | NIC COMPONENTS CORP | Active |  | Preferred
4 | Part | Boards/CAD Parts/Component | 745000036635 | 470-80452 | RES MF 10K 1/16W 1% 0402 | RFS | A |  | 16 | R1,R2,R3,R21,R26,R36,R39,R41,R57,R58,R59,R60,R86,R106,R116,R207 | 0 |  | 294588 | RC0402FR-1310KL | Yageo | Active |  | Alternate
4 | Part | Boards/CAD Parts/Component | 745000036664 | 470-80487 | RES MF 1.5K 1/16W 1% 0402 | RFS | A |  | 1 | R155 | 0 |  | 234489 | CR0402-FX-1501GLF | BOURNS | Active |  | Preferred
4 | Part | Boards/CAD Parts/Component | 745000051831 | 480-75317 | TRANS MOSFET N-CH 30V .1A SOT-323 | RFS | A |  | 1 | Q1 | 0 |  | 213347 | 2SK3018T106 | ROHM | Active |  | Preferred
4 | Part | Boards/CAD Parts/Component | 745000022294 | 480-76978 | DIODE SCH 1A 30V MICROSMP SMT | RFS | B |  | 2 | D3,D4 | 0 |  | 257745 | MSS1P3L-M3/89A | VISHAY INTERTECHNOLOGY | Active |  | Preferred
4 | Part | Boards/CAD Parts/Component | 745000022294 | 480-76978 | DIODE SCH 1A 30V MICROSMP SMT | RFS | B |  | 0 | D6 | 4801 | DNP | 257745 | MSS1P3L-M3/89A | VISHAY INTERTECHNOLOGY | Active |  | Preferred
4 | Part | Boards/CAD Parts/Component | 745000022836 | 480-78454 | DIODE BIDIR 1-LINE ESD PROT 0.4pF 6V 2.5A AEC-Q101 SOD882 | RFS | A |  | 2 | D7,D8 | 0 |  | 292671 | PESD5V0F1BL,315 | Nexperia | Active |  | Preferred
4 | Part | Boards/CAD Parts/Component | 745000044942 | 510-78653 | SW SP PB 50mA 16V SMT | RFS | A |  | 3 | SW1,SW2,SW3 | 0 |  | 214376 | 434123025826 | WURTH ELEKTRONIK EISOS GMBH & CO. KG (ELECTRONIC & ELECTROMEHANICAL COMP) | ROHS Active |  | Preferred
4 | Part | Boards/CAD Parts/Component | 745000013038 | 150-79103 | CAP CER 1000pF 2KV 10% X7R 1206 | RFS | A |  | 2 | C60,C61 | 0 |  | 202696 | 1206B102K202CT | WALSIN TECHNOLOGY CORP. | Active |  | Preferred
4 | Part | Boards/CAD Parts/Component | 745000013038 | 150-79103 | CAP CER 1000pF 2KV 10% X7R 1206 | RFS | A |  | 2 | C60,C61 | 0 |  | 217829 | 202R18W102KV4E | JOHANSON DIELECTRICS | Active | 260±5°C for 10 seconds.Test standards and procedures per MIL-STD-202 and MIL-C-123 | Alternate
4 | Part | Boards/CAD Parts/Component | 745000015494 | 150-81891 | CAP CER 1uF 16V 20% X5R 0603 | RFS | A |  | 11 | C6,C10,C13,C17,C25,C42,C45,C46,C49,C64,C65 | 0 |  | 239810 | 885012106017 | Wurth Electronik GmbH & Co. KG (PCB) | ROHS Active |  | Preferred
4 | Part | Boards/CAD Parts/Component | 745000026445 | 180-78156 | IND FER BEAD 330OHM@100MHZ 1.7A 0603 | RFS | A |  | 2 | L3,L6 | 0 |  | 260841 | MPZ1608S331A | TDK | Active |  | Preferred
4 | Part | Boards/CAD Parts/Component | 745000026445 | 180-78156 | IND FER BEAD 330OHM@100MHZ 1.7A 0603 | RFS | A |  | 2 | L3,L6 | 0 |  | 300107 | UPZ1608E331-1R7TF | Shenzhen Sunlord Electronics Co., Ltd | ROHS Active |  | Alternate
4 | Part | Boards/CAD Parts/Component | 745000026542 | 180-78270 | IND WW PWR 1.5uH@1MHZ 2A 20% 2520 | RFS | A |  | 1 | L2 | 0 |  | 276777 | SPH252012H1R5MT | Shenzhen Sunlord Electronics Co., Ltd | Active |  | Preferred
4 | Part | Boards/CAD Parts/Component | 745000046511 | 210-80192 | HDR 2X5 TH 50MIL CTR 167H AU 91L | RFS | A1 | ECO30003120 | 1 | J23 | 0 |  | 201710 | 0922S0205011N6T-2LF | ANYTRONIC CORPORATION LIMITED | ROHS Active |  | Preferred
4 | Part | Boards/CAD Parts/Component | 745000046511 | 210-80192 | HDR 2X5 TH 50MIL CTR 167H AU 91L | RFS | A1 | ECO30003120 | 1 | J23 | 0 |  | 272396 | GRPB052VWVN-RC | SULLINS ELECTRONICS CORP | ROHS Active |  | Alternate
4 | Part | Boards/CAD Parts/Component | 745000047622 | 210-81617 | CON 1X8 SKT TH 100MIL SP 344H AU 118L | RFS | A |  | 2 | J5,J6 | 0 |  | 201293 | 08001S3 0811-29RF | ANYTRONIC CORPORATION LIMITED | ROHS Active |  | Preferred
4 | Part | Boards/CAD Parts/Component | 745000047745 | 210-81774 | CON 2X6 SKT SHRD TH 100MIL CTR 345H AU 126L | RFS | A |  | 1 | J4 | 0 |  | 201297 | 08010S31211-29RF | ANYTRONIC CORPORATION LIMITED | ROHS Active |  | Preferred
4 | Part | Boards/CAD Parts/Component | 745000040188 | 211-76642 | TEST POINT PAD 30MIL DIA SMT, NO PART TO ORDER | RFS | A |  | 30 | TP2,TP3,TP4,TP5,TP6,TP7,TP8,TP9,TP10,TP11,TP12,TP13,TP14,TP15,TP16,TP17,TP18,TP19,TP20,TP21,TP22,TP23,TP24,TP25,TP26,TP27,TP28,TP29,TP30,TP31 | 0
4 | Part | Boards/CAD Parts/Component | 745000031863 | 230-78676 | XTAL 32.768kHz 12.5pF 1.05pF 20ppm SMT | RFS | A |  | 1 | Y2 | 0 |  | 226270 | 830009678 | Wurth Electronik GmbH & Co. KG (PCB) | ROHS Active |  | Preferred
4 | Part | Boards/CAD Parts/Component | 745000019384 | 312-81473 | IC CC LOGIC USB TYPE-C 2.7-5.5V X2QFN12 | RFS | A |  | 1 | U5 | 0 |  | 263288 | PTN5150AHXMP | NXP SEMICONDUCTOR | Active |  | Preferred
4 | Part | Boards/CAD Parts/Component | 745000034503 | 470-75356 | RES MF 2.0K 1/16W 1% 0402 | RFS | A1 |  | 3 | R134,R204,R205 | 0 |  | 234511 | CR0402-FX-2001GLF | BOURNS | ROHS Active |  | Preferred
4 | Part | Boards/CAD Parts/Component | 745000034503 | 470-75356 | RES MF 2.0K 1/16W 1% 0402 | RFS | A1 |  | 3 | R134,R204,R205 | 0 |  | 255259 | CR0402-16W-2001FT | VENKEL COMPANY | ROHS Active |  | Alternate
4 | Part | Boards/CAD Parts/Component | 745000034503 | 470-75356 | RES MF 2.0K 1/16W 1% 0402 | RFS | A1 |  | 3 | R134,R204,R205 | 0 |  | 269306 | RC0402FR-072KL | YAGEO AMERICA | Active |  | Alternate
4 | Part | Boards/CAD Parts/Component | 745000034503 | 470-75356 | RES MF 2.0K 1/16W 1% 0402 | RFS | A1 |  | 3 | R134,R204,R205 | 0 |  | 269343 | RC0402FR-132KL | YAGEO AMERICA | Active |  | Alternate
4 | Part | Boards/CAD Parts/Component | 745000034503 | 470-75356 | RES MF 2.0K 1/16W 1% 0402 | RFS | A1 |  | 3 | R134,R204,R205 | 0 |  | 302462 | WR04X2001FTL | WALSIN TECHNOLOGY CORP. | ROHS Active |  | Alternate
4 | Part | Boards/CAD Parts/Component | 745000034507 | 470-75360 | RES MF 49.9 OHM 1/16W 1% 0402 | RFS | A1 |  | 10 | R62,R63,R64,R65,R73,R76,R77,R78,R83,R84 | 0 |  | 252768 | CR02FL6-49R9 | THYE MING TECH CO LTD | ROHS Active | No MDS available per Mfg | Alternate
4 | Part | Boards/CAD Parts/Component | 745000034507 | 470-75360 | RES MF 49.9 OHM 1/16W 1% 0402 | RFS | A1 |  | 10 | R62,R63,R64,R65,R73,R76,R77,R78,R83,R84 | 0 |  | 253025 | CR040216W49R9FT | VENKEL COMPANY | ROHS Active |  | Alternate
4 | Part | Boards/CAD Parts/Component | 745000034507 | 470-75360 | RES MF 49.9 OHM 1/16W 1% 0402 | RFS | A1 |  | 10 | R62,R63,R64,R65,R73,R76,R77,R78,R83,R84 | 0 |  | 255289 | CR0402-FX-49R9GLF | BOURNS | Active |  | Preferred
4 | Part | Boards/CAD Parts/Component | 745000034507 | 470-75360 | RES MF 49.9 OHM 1/16W 1% 0402 | RFS | A1 |  | 10 | R62,R63,R64,R65,R73,R76,R77,R78,R83,R84 | 0 |  | 264029 | RC0402FR-0749R9L | Yageo | ROHS Active |  | Alternate
4 | Part | Boards/CAD Parts/Component | 745000034507 | 470-75360 | RES MF 49.9 OHM 1/16W 1% 0402 | RFS | A1 |  | 10 | R62,R63,R64,R65,R73,R76,R77,R78,R83,R84 | 0 |  | 275650 | WR04X49R9FTL | WALSIN TECHNOLOGY CORP. | ROHS Active |  | Alternate
4 | Part | Boards/CAD Parts/Component | 745000034694 | 470-75626 | RES MF 4.7K 1/16W 5% 0402 | RFS | A |  | 0 | R51,R52,R88,R89,R90,R91,R92,R93,R95,R96 | 4704 | DNP | 230860 | CR0402-JW-472GLF | BOURNS | ROHS Active |  | Alternate
4 | Part | Boards/CAD Parts/Component | 745000034694 | 470-75626 | RES MF 4.7K 1/16W 5% 0402 | RFS | A |  | 0 | R51,R52,R88,R89,R90,R91,R92,R93,R95,R96 | 4704 | DNP | 253022 | CR040216W472JT | VENKEL COMPANY | ROHS Active | 260*C | Alternate
4 | Part | Boards/CAD Parts/Component | 745000034694 | 470-75626 | RES MF 4.7K 1/16W 5% 0402 | RFS | A |  | 0 | R51,R52,R88,R89,R90,R91,R92,R93,R95,R96 | 4704 | DNP | 269656 | RC73L2Z472JTF | SMEC | Obsolete |  | Disqualified
4 | Part | Boards/CAD Parts/Component | 745000034694 | 470-75626 | RES MF 4.7K 1/16W 5% 0402 | RFS | A |  | 0 | R51,R52,R88,R89,R90,R91,R92,R93,R95,R96 | 4704 | DNP | 275648 | WR04X472 JTL | WALSIN TECHNOLOGY CORP. | ROHS Active |  | Alternate
4 | Part | Boards/CAD Parts/Component | 745000034694 | 470-75626 | RES MF 4.7K 1/16W 5% 0402 | RFS | A |  | 0 | R51,R52,R88,R89,R90,R91,R92,R93,R95,R96 | 4704 | DNP | 290761 | NRCL04J472TRF | NIC COMPONENTS CORP | Active |  | Preferred
4 | Part | Boards/CAD Parts/Component | 745000034673 | 470-75591 | RES MF 100 OHM 1/16W 5% 0402 | RFS | A |  | 2 | R188,R189 | 0 |  | 230754 | CR040216W101JT | VENKEL COMPANY | ROHS Active |  | Alternate
4 | Part | Boards/CAD Parts/Component | 745000034673 | 470-75591 | RES MF 100 OHM 1/16W 5% 0402 | RFS | A |  | 2 | R188,R189 | 0 |  | 262403 | NRCL04J101TRF | NIC COMPONENTS CORP | Active |  | Preferred
4 | Part | Boards/CAD Parts/Component | 745000034673 | 470-75591 | RES MF 100 OHM 1/16W 5% 0402 | RFS | A |  | 2 | R188,R189 | 0 |  | 255293 | CR0402-JW-101GLF | BOURNS | ROHS Active |  | Alternate
4 | Part | Boards/CAD Parts/Component | 745000034694 | 470-75626 | RES MF 4.7K 1/16W 5% 0402 | RFS | A |  | 10 | R32,R67,R68,R94,R148,R149,R208,R209,R210,R211 | 0 |  | 230860 | CR0402-JW-472GLF | BOURNS | ROHS Active |  | Alternate
4 | Part | Boards/CAD Parts/Component | 745000034694 | 470-75626 | RES MF 4.7K 1/16W 5% 0402 | RFS | A |  | 10 | R32,R67,R68,R94,R148,R149,R208,R209,R210,R211 | 0 |  | 253022 | CR040216W472JT | VENKEL COMPANY | ROHS Active | 260*C | Alternate
4 | Part | Boards/CAD Parts/Component | 745000034694 | 470-75626 | RES MF 4.7K 1/16W 5% 0402 | RFS | A |  | 10 | R32,R67,R68,R94,R148,R149,R208,R209,R210,R211 | 0 |  | 269656 | RC73L2Z472JTF | SMEC | Obsolete |  | Disqualified
4 | Part | Boards/CAD Parts/Component | 745000034694 | 470-75626 | RES MF 4.7K 1/16W 5% 0402 | RFS | A |  | 10 | R32,R67,R68,R94,R148,R149,R208,R209,R210,R211 | 0 |  | 275648 | WR04X472 JTL | WALSIN TECHNOLOGY CORP. | ROHS Active |  | Alternate
4 | Part | Boards/CAD Parts/Component | 745000034694 | 470-75626 | RES MF 4.7K 1/16W 5% 0402 | RFS | A |  | 10 | R32,R67,R68,R94,R148,R149,R208,R209,R210,R211 | 0 |  | 290761 | NRCL04J472TRF | NIC COMPONENTS CORP | Active |  | Preferred
4 | Part | Boards/CAD Parts/Component | 745000035054 | 470-76240 | RES MF 100K 1/16W 1% 0402 | RFS | A1 |  | 7 | R33,R103,R124,R144,R145,R146,R147 | 0 |  | 230798 | CR0402-FX-1003GLF | BOURNS | ROHS Active |  | Alternate
4 | Part | Boards/CAD Parts/Component | 745000035054 | 470-76240 | RES MF 100K 1/16W 1% 0402 | RFS | A1 |  | 7 | R33,R103,R124,R144,R145,R146,R147 | 0 |  | 231714 | CRCW0402100KFKEDC | VISHAY INTERTECHNOLOGY | Active |  | Alternate
4 | Part | Boards/CAD Parts/Component | 745000035054 | 470-76240 | RES MF 100K 1/16W 1% 0402 | RFS | A1 |  | 7 | R33,R103,R124,R144,R145,R146,R147 | 0 |  | 262399 | NRCL04F1003TRF | NIC COMPONENTS CORP | Active |  | Preferred
4 | Part | Boards/CAD Parts/Component | 745000035054 | 470-76240 | RES MF 100K 1/16W 1% 0402 | RFS | A1 |  | 7 | R33,R103,R124,R144,R145,R146,R147 | 0 |  | 255087 | CR02FL6--100K | THYE MING TECH CO LTD | ROHS Active | No MDS available per Mfg | Alternate
4 | Part | Boards/CAD Parts/Component | 745000035054 | 470-76240 | RES MF 100K 1/16W 1% 0402 | RFS | A1 |  | 7 | R33,R103,R124,R144,R145,R146,R147 | 0 |  | 292773 | RC0402FR-07100KL | YAGEO AMERICA | ROHS Active |  | Alternate
4 | Part | Boards/CAD Parts/Component | 745000035054 | 470-76240 | RES MF 100K 1/16W 1% 0402 | RFS | A1 |  | 0 | R54 | 4703 | DNP | 230798 | CR0402-FX-1003GLF | BOURNS | ROHS Active |  | Alternate
4 | Part | Boards/CAD Parts/Component | 745000035054 | 470-76240 | RES MF 100K 1/16W 1% 0402 | RFS | A1 |  | 0 | R54 | 4703 | DNP | 231714 | CRCW0402100KFKEDC | VISHAY INTERTECHNOLOGY | Active |  | Alternate
4 | Part | Boards/CAD Parts/Component | 745000035054 | 470-76240 | RES MF 100K 1/16W 1% 0402 | RFS | A1 |  | 0 | R54 | 4703 | DNP | 262399 | NRCL04F1003TRF | NIC COMPONENTS CORP | Active |  | Preferred
4 | Part | Boards/CAD Parts/Component | 745000035054 | 470-76240 | RES MF 100K 1/16W 1% 0402 | RFS | A1 |  | 0 | R54 | 4703 | DNP | 255087 | CR02FL6--100K | THYE MING TECH CO LTD | ROHS Active | No MDS available per Mfg | Alternate
4 | Part | Boards/CAD Parts/Component | 745000035054 | 470-76240 | RES MF 100K 1/16W 1% 0402 | RFS | A1 |  | 0 | R54 | 4703 | DNP | 292773 | RC0402FR-07100KL | YAGEO AMERICA | ROHS Active |  | Alternate
4 | Part | Boards/CAD Parts/Component | 745000035098 | 470-76474 | RES MF 5.1K 1/16W 1% 0402 | RFS | A1 |  | 2 | R112,R113 | 0 |  | 252774 | CR02FL6--5K1 | THYE MING TECH CO LTD | ROHS Active | No MDS available per Mfg | Preferred
4 | Part | Boards/CAD Parts/Component | 745000039145 | 470-83213 | RES MF 2.2K 1/16W 1% 0402 | RFS | A |  | 1 | R135 | 0 |  | 253054 | CR0402-FX-2201GLF | Bourns Inc. | ROHS Active |  | Preferred
4 | Part | Boards/CAD Parts/Component | 745000039145 | 470-83213 | RES MF 2.2K 1/16W 1% 0402 | RFS | A |  | 0 | R140,R141 | 4706 | DNP | 253054 | CR0402-FX-2201GLF | Bourns Inc. | ROHS Active |  | Preferred
4 | Part | Boards/CAD Parts/Component | 745000039146 | 470-83214 | RES MF 62 OHM 1/4W 1% AEC-Q200 0805 | RFS | A |  | 2 | R98,R102 | 0 |  | 297932 | SG73P2ATTD62R0F | KOA SPEER | ROHS Active |  | Preferred
4 | Part | Boards/CAD Parts/Component | 745000022761 | 480-78365 | DIODE SCH DUAL CC 200MA 30V SOT23 | RFS | A |  | 1 | D17 | 0 |  | 227482 | BAT54C-7-F | DIODES INC | Active |  | Preferred
4 | Part | Boards/CAD Parts/Component | 745000023142 | 480-78843 | DIODE TVS ARRAY 3 5.5V SLP1616P6 | RFS | A |  | 0 | U12 | 4804 | DNP | 293219 | RClamp0854P.TCT | SEMTECH CORP | Active |  | Preferred
4 | Part | Boards/CAD Parts/Component | 745000023142 | 480-78843 | DIODE TVS ARRAY 3 5.5V SLP1616P6 | RFS | A |  | 1 | U4 | 0 |  | 293219 | RClamp0854P.TCT | SEMTECH CORP | Active |  | Preferred
4 | Part | Boards/CAD Parts/Component | 745000011472 | 150-30180 | CAP CER 12PF 25V 5% C0G 0402 | RFS | A |  | 0 | C96,C97 | 1505 | DNP | 249584 | C0402C120J3GAC7867 | KEMET | Active |  | Preferred
4 | Part | Boards/CAD Parts/Component | 745000011542 | 150-30269 | CAP CER 56PF 50V 5% C0G 0402 | RFS | A |  | 2 | C66,C68 | 0 |  | 249544 | C0402C0G500-560JNE | VENKEL COMPANY | ROHS Active |  | Alternate
4 | Part | Boards/CAD Parts/Component | 745000011706 | 150-75169 | CAP CER 47pF 50V 5% C0G 0402 | RFS | A |  | 4 | C87,C89,C92,C95 | 0 |  | 200452 | 04025A470JAT2A | AVX | ROHS Active |  | Alternate
4 | Part | Boards/CAD Parts/Component | 745000011706 | 150-75169 | CAP CER 47pF 50V 5% C0G 0402 | RFS | A |  | 4 | C87,C89,C92,C95 | 0 |  | 200517 | 0402CG470J500NT | FENGHUA | Active |  | Alternate
4 | Part | Boards/CAD Parts/Component | 745000011706 | 150-75169 | CAP CER 47pF 50V 5% C0G 0402 | RFS | A |  | 4 | C87,C89,C92,C95 | 0 |  | 247298 | GMC04CG470J50NT-LF | CAL-CHIP | ROHS Active |  | Preferred
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

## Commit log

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2025-01-16 Added regulators and reverse polarity protection datasheets
2025-01-17 Added symbol and footprint library locations table. Added NXP logo and first on schematic sheets. Created sheets for each part of the schematic. Added the important components needed in each sheet
    [communication.kicad_sch, flow_max.kicad_pcb, flow_max.kicad_sch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]
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2025-01-17 Added pin assignment to MCXN947 for the communication lines, Debugger, ISP_Mode and optional GPIO/SD card
    [mcu_io_1.kicad_sch, mcu_io_2.kicad_sch, mcu_usb_power.kicad_sch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]
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2025-02-03 Added in the schematic common mode choke filters and TVS diodes to parts where it is needed. Made the polarity protection circuit in schematic. Put placeholders for power supply regulators in schemat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
    [communication.kicad_sch, flow_max.kicad_pcb, mcu_io_1.kicad_sch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]
2025-04-16 Created kicad project for MCXN-T1 Optical Flow
    Created kicad project for MCXN-T1 Optical Flow add-on board.
    Created initial schematic design. Added board-to-board connectors with correct pinouts. Added sensors in schematic.
    [board-to-board.kicad_sch, sensors.kicad_sch, spinali_add-on_optical_flow.kicad_pcb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]
2025-05-20 Updated schematic and started on layout
    - Added LED driver circuit for PAA3905 LED_SYNC.
    - Started on layouting PCB.
    [board-to-board.kicad_sch, sensors.kicad_sch, spinali_add-on_optical_flow.kicad_pcb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]
2025-05-22 Finished layout and schematic
    - Added cognipilot logo to silkscreen.
    - Added test points to PAA3905E1 data signals.
    [board-to-board.kicad_sch, bom.csv, designators.csv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]
2025-05-27 Finalized design for V0 production
    - Added correct BOM and Gerbers
    [BOM_spinali_add-on_optical_flow.csv, sensors.kicad_sch, spinali_add-on_optical_flow.kicad_pcb]
2025-05-30 Created schematic of GNSS NEO-F9P add-on board
    - Created schematic for GNSS NEO-F9P.
    - Finished schematic for initial review.
    - Copied PCB layout from optical flow board and removed unnecessary footprints.
    [board-to-board.kicad_sch, gnss.kicad_sch, sensors.kicad_sch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]
2025-06-02 Add Switches
    Update to add switches.
    Poked around with antenna placement on board
    (note i'm still getting oriented to KiCad vs previous tools)
    [board-to-board.kicad_sch, gnss.kicad_sch, sensors.kicad_sch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]
2025-06-02 Update to include Spinali Dirs locally
    Hopefully this doesn't impact others? (@Youri)
    FYI i'm using KiCad 9
    [spinali_add-on_GNSS_F9P.kicad_pcb, spinali_add-on_GNSS_F9P.kicad_sch]
2025-06-04 Finished schematic of GNSS for initial review
    - Added some parts for the BOM.
    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
    [gnss.kicad_sch, sensors.kicad_sch]
2025-06-04 Fixed merge corruption
    - Fixed corruption caused by previous commit.
    - Added features added by Iain.
    [board-to-board.kicad_sch, gnss.kicad_sch, sensors.kicad_sch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]
2025-06-06 Update schematics
    Mapped caps/resistors
    trial placements on PCB
    Still needs LEDs
    [board-to-board.kicad_sch, gnss.kicad_sch, sensors.kicad_sch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]
2025-06-09 Parts placement
    initial parts placement.
    What do we think about Button placement?
    Still need to:
    - spend time on the Mag. Adjust passives and ensure orientations
    - Compare LEDs with what we've used in the past
    - Make sure BOM is readily available parts.
    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
    [gnss.kicad_sch, sensors.kicad_sch, spinali_add-on_GNSS_F9P.kicad_pcb]
2025-06-10 progress sch and layout
    Added regulator for USB (may not be necessary)
    Question about the two 3v3 sources (i2C pullup to 3v3, whereas rest of chip is the local regulator.
    NOTE - Power traces are temporary with 6 mil. set the net class, but it didn't seem to force a change. Will research tomorrow.
    Trial place ment looks ok.
    Need to review stripline / RF trace details.
    [gnss.kicad_sch, spinali_add-on_GNSS_F9P.kicad_pcb]
2025-06-19 ongoing updates to layout
    Some suggested schematics changes noted
    [gnss.kicad_sch, sensors.kicad_sch, spinali_add-on_GNSS_F9P.kicad_pcb]
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2025-06-25 DRC and other adjustments
    Still not "ready". Needs review of comments on schematics to align with layout
    [board-to-board.kicad_sch, gnss.kicad_sch, sensors.kicad_sch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]
2025-07-09 Just and update of minor stuff after having it open for a bit.
    [board-to-board.kicad_sch, gnss.kicad_sch]
2025-07-09 rotate MAG
    Rotated MAG and make layout adjustments
    [gnss.kicad_sch, spinali_add-on_GNSS_F9P.kicad_pcb]
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2025-07-10 Clear DRC
    - still needs updates and checks as per notes on schematics (switch etc.)
    [spinali_add-on_GNSS_F9P.kicad_pcb]
2025-07-14 cleanup and attach GPX-fix signal to connector
    [board-to-board.kicad_sch, gnss.kicad_sch, spinali_add-on_GNSS_F9P.kicad_pcb]
2025-08-07 Updated Optical flow add-on board
    - Added patch for inverting LED_SYNC signal coming from PAA3905.
    [sensors.kicad_sch, spinali_add-on_optical_flow.kicad_pcb]
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2025-08-14 Update spinali_add-on_GNSS_F9P.kicad_pcb
    REworked RF section to antenna
    [spinali_add-on_GNSS_F9P.kicad_pcb]
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2025-08-21 Changing SWitches and Battery symbol
    Changing SW1 and SW2 to a panasonic tactile switch, Removing MP error in Battery symbol, Removing a lot of DRC error and DRC warnings
    [gnss.kicad_sch, spinali_add-on_GNSS_F9P.kicad_pcb]
2025-08-25 Cleanup of git
    Committing to main so it can be the ground truth before branching again.
    [gnss.kicad_sch]
2025-08-28 Iain rc3 review, RevX1 ready for quote (#9)
    * Fixed to DRC errors
    * Fix DRC errors
    * Lib and layout updates
    Library fixes
    REmove RF power injection
    Change switches.
    Work on DRC errors.
    RE-do USB differential pairs.
    * Fix 3d models
    Fix 3d Models and parts that seem to have reverted to old footprints
    (I had changed them, but somthing caused them to revert back. May have been from a crash, or maybe from "update board from schematics"
    * Clean up routing
    Add Silkscreen labels for LEDs
    Clean up routing for GND pours
    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
    [BOM_spinali_add-on_optical_flow.csv, board-to-board.kicad_sch, sensors.kicad_sch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]
2025-09-02 Cleaned up kicad folders and created production files for OFLO
    - Removed schematic from OFLO board in GNSS folder.
    - Create all production files of OFLO board (e.g. Gerbers, step, schematics, BOM, position) and put them in the production folder.
    [BOM_spinali_add-on_GNSS_F9P.csv, BOM_spinali_add-on_optical_flow.csv, board-to-board.kicad_sch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]
2025-09-02 Updated layout and fixed silkscreen
    - Removed silkscreen from added resistors.
    - Removed silkscreen arrow.
    - Added more space between AFBR-S50LX85D pads and components that are close to it.
    [spinali_add-on_optical_flow.kicad_pcb]
2025-09-02 Updated silkscreen and created production files
    - Added silkscreen reference designators to all components.
    - Created Gerber, position and step file.
    [spinali_add-on_optical_flow.kicad_pcb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]
2025-09-04 Power adjacent ethernet draft (#10)
    Clean up schematics to show net classes
    Update all power traces with PWR netclass
    * RC3 ready for fab
    Still needs BOM table update.
    * FIX ERC errors
    There were a few minor ERC error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
    [16L-6X6-LGA_Assembly_20230207_V1.2.STEP, BOM_spinali_add-on_optical_flow.csv, EAP_conn_and_power.kicad_sch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]
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2025-09-17 Sept13 adjustments (#14)
    * work on USB diff pair
    Not complete yet
    * Update spinali_mcxn_t1_f9p.kicad_pcb
    Adjustments to USB-C diff traces near the connector.
    * Correct footprints for switches and battery connector
    for some reason these keep getting "unlinked"
    * Update spinali_mcxn_t1_f9p.kicad_pcb
    Added 3d footprints (back) for Battery connector
    Adede 3d footprint for UFL connector
    [gnss.kicad_sch, spinali_mcxn_t1_f9p.kicad_pcb]
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2025-10-20 Updated IO board layout to 4-layers
    - Re-routed a bit so 4-layers is possible.
    [spinali_mcxn_t1_io.kicad_pcb]
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2025-10-23 Started improving layout
    - Fixed library references in footprints etc.
    - Fixed USB differential pair length matched
    - Added GND vias to some parts where needed. (still needs more)
    - Changed some routing
    [gnss.kicad_sch, spinali_mcxn_t1_f9p.kicad_pcb]
2025-10-23 Improved layout further
    - Added more GND vias at places.
    - Rerouted some parts.
    - Moved traces under F9P module.
    [spinali_mcxn_t1_f9p.kicad_pcb]
2025-10-28 Updated schematic and layout after review (ready for production)
    - Replaced TVS diode at ESC1 and ESC2 connector with higher voltage one.
    - Replaced MUTAG7104 TVS with single TVS at some places to reduce cost.
    - Added 1k5 pull-down resistor on GPS safety switch.
    - Generated all production files.
    [BOM_spinali_mcxn_t1_oflo.csv, bom.csv, designators.csv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]
2026-02-13 Updated MCXN-T1 IO board
    - Fixed that JST GH connectors are now the correct part number.
    - Updated silkscreen positioning.
    - Generated production files for Eurocircuits (global) and JLCPCB
    [BOM_spinali_mcxn_t1_io.csv, bom.csv, designators.csv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]
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2026-03-31 Review gps again (#20)
    * Add misc grounds
    * layout adjustments and DRC
    Adjust GNSS trace according to reviewed rules (center feed pad). Trace is short enough that mismatch impedance is not going to impact the signal.
    * Review inner layers
    * More trace reviwe
    Edit 3v3 power trace for GNSS module. Other minor reviews
    * F9P fixed DRC errors.
    - Fixed clearance issue.
    - Fixed ground being unconnected.
    ---------
    [spinali_mcxn_t1_f9p.kicad_pcb]
2026-07-28 MR-MCXN-T1 IO update to production version X1 (#22)
    - Updated MR-MCXN-T1 IO board for production version X1
    - Changed R10 and R11 to 10k and DNP, so they work with the latest MR-MCXN-T1 hub version X1
    - Changed I2C1 and I2C2 connector names to I3C and I2C.
    - Updated page information to version X1
    - Updated gitignore to ignore production folders
    - Deleted kicad/spinali_mcxn_t1_io/production directory
    [BOM_spinali_mcxn_t1_io.csv, board-to-board.kicad_sch, bom.csv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]
2026-08-21 Rev A production ready: schematic, layout and BOM fixes
    - Rev A production ready.
    - Update Resistor R10 on PCB
    - Review DNP and re-add I2C pullups (no longer DNP)
    - add silkscreen for revision
    - Revision in title block
    - add revision table
    - add silkscreen for battery polarity.
    - Changed 0R pull-up / pull-down resistors where possible to 10k for current protection.
    - Fixed R13 footprint to correct package -> 0603 (was 0402).
    - Improved BOM headers.
    - Added Project text variables so Revision, Title, Designers, etc. is set automatically at multiple places.
    - Updated all footprints so they match the library again (previously gave DRC error). Now 3D models also work again.
    - Moved Time Pulse LED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
    [board-to-board.kicad_sch, gnss.kicad_sch, sensors.kicad_sch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]
2026-08-24 Added Rev-A in MR-MCXN-T1-IO
    - Added Rev-A in schematic and layout
    - Created production files
    [board-to-board.kicad_sch, io1.kicad_sch, io2.kicad_sch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]
2026-08-24 Added Rev-A in MR-MCXN-T1-OFLO
    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
    [board-to-board.kicad_sch, sensors.kicad_sch, spinali_mcxn_t1_oflo.kicad_pcb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]
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
